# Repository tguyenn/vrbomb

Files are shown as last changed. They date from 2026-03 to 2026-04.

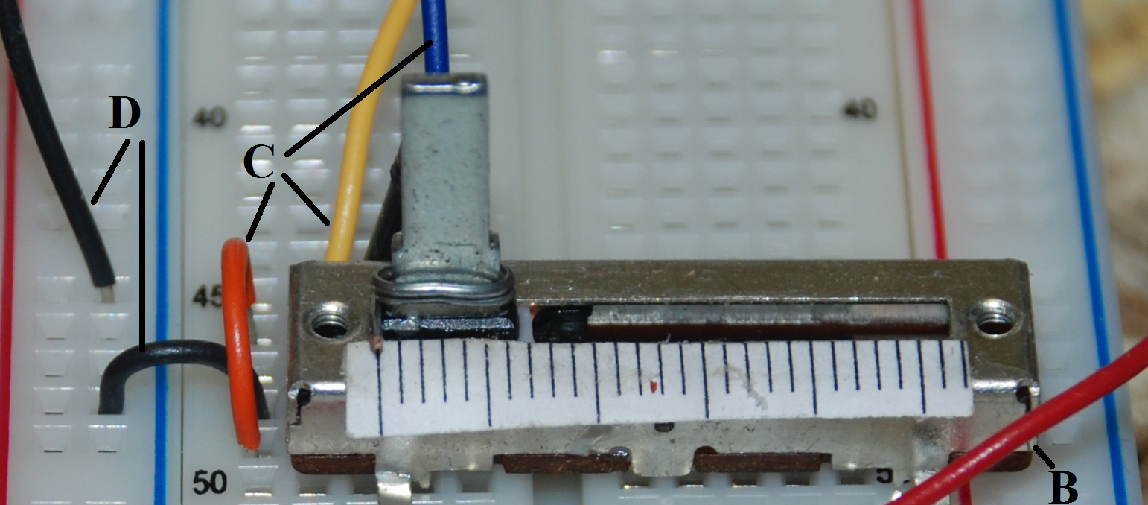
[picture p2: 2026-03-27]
firmware/Main_Board/Lab7_slidepot.png

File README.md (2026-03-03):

Review Assignment Due Date (https://classroom.github.com/a/UF6_VorU)
## 0 Repository Structure

The typical explanation for the repo structure. Lab specific instructions can be
found further below.

### 0.1 HW

The `hw` folder should contain your schematic and board files for your PCB or
circuits. In labs 1-5 and 10, you will be creating schematics for your circuit
in KiCad. 

### 0.2 SW

The `sw` folder should contain your application firmware and software written
for the lab. The `sw/inc` folder contains firmware drivers written for you by
Professor Valvano. Feel free to write your own (in fact, in some labs, you may
be required to write your own).

You can place any other source files in the `sw` folder. TAs will look at the
files you create and/or modify for software quality and for running your
project.

### 0.3 Resources

A couple files are provided in the Resources folder so you don't have to keep
searching for that one TI document. Some of them are immediately useful, like
the TM4C datasheet. Others may be useful for your final project, like the
TM4C_System_Design_Guidelines page.

### 0.4 Git and Github

We will extensively use Git and Github for managing lab projects. This makes it
easier for TAs to grade and help debug the project by allowing us to see commit
histories, maintain a common project structure, and likewise, it makes it easier
for students to collaborate with partners, merge different codebases, and to
debug their work by having a history of commits.

Two common ways of using Git and Github are [Github Desktop](https://desktop.github.com/) and the [command line](https://git-scm.com/downloads).
[Tutorials](https://dev.to/mollynem/git-github--workflow-fundamentals-5496) are also abundant on the net for you to peruse. We've provided a cheatsheet for git
in the Resources folder.

It is highly recommended to make the most out of Git, even if you've never used
it before. Version control will save you a lot of suffering, and tools like Git
or SVN are ubiquitous in the industry.

A gitignore file is added to the root of this repo that may prevent specific
files from being tagged to the repo. This are typically autogenerated output
files we don't care about, but sometimes other stuff (like .lib files) falls
through that we want. Feel free to modify if necessary.

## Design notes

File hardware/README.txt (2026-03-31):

- please pretty please order 10 of our peripheral boards

- look inside each project directory for production files 

thank you :)

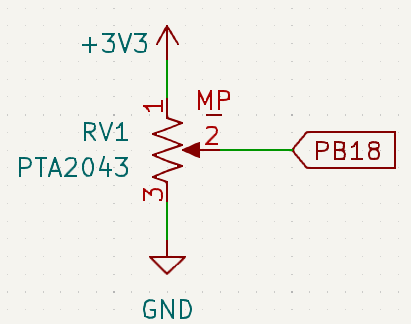
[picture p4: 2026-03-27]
firmware/Main_Board/Lab7Circuit.png

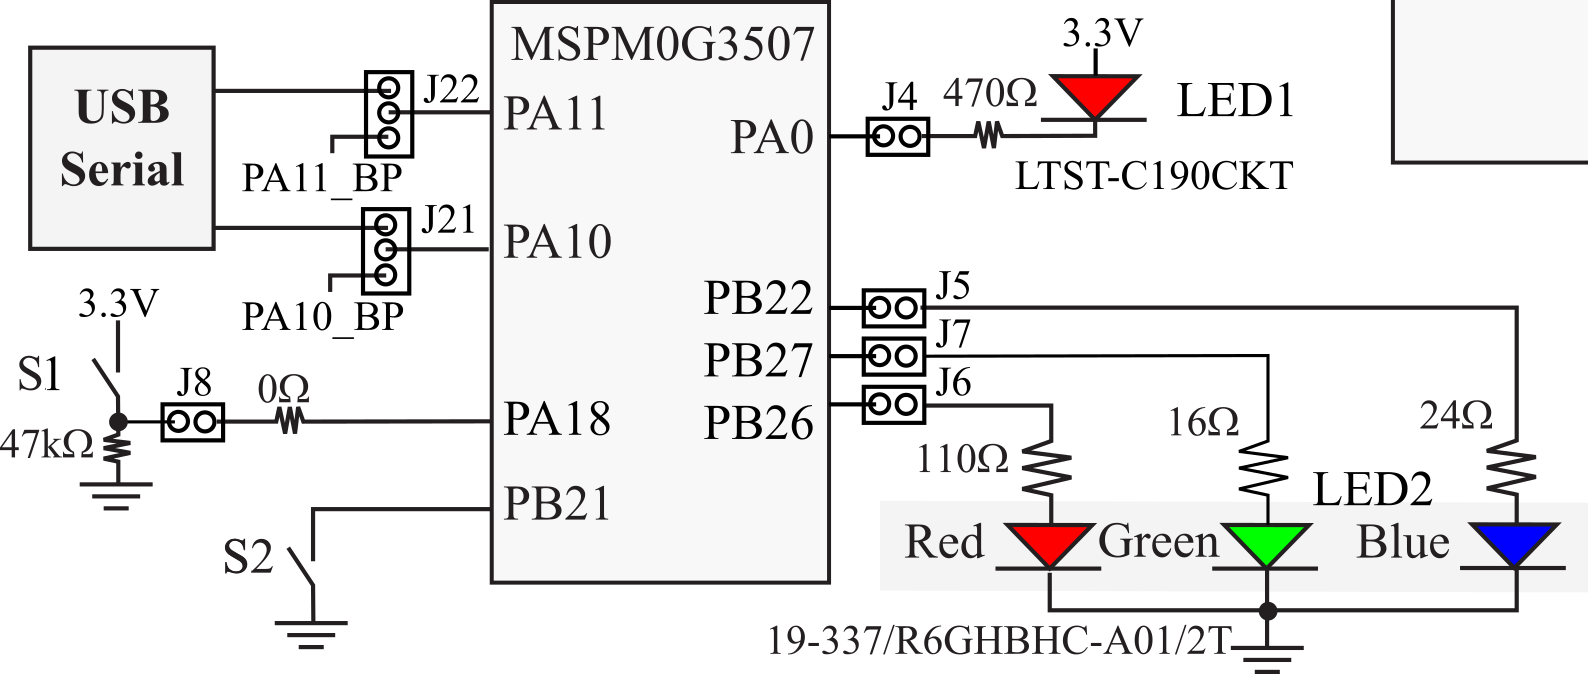
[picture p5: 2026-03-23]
firmware/inc/LaunchPad.png

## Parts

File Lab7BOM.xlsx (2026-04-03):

Bill of Materials |  |  | 2025-01-07 | "not free" means you have to buy it |  | "free sample" means you have to order it
ECE445L Spring 2025 |  |  | EE445L pays for the PCB | "Cabinet means in one of the six black cabinets in professsor's office (bring a print out of your SCH")
 |  |  |  | "Professor" means ask your professor quantity and style will vary (bring a print out of your SCH circuit)
Qty Note | REF DES Note (http://projects.ece.utexas.edu/valvano/wiki/doku.php?id=pcbartist:schematics) |  |  | "Box means in box in your professor's office (bring a print out of your SCH circuit)
Quantity | REF DES | Type | Description | Mfg. P/N | Distributor | P/N | Unit cost | Cost | Where to get it?
60 |  |  | Magnets | - | Mouser | https://www.amazon.com/gp/product/B0CCXY6WBR/ref=ewc_pr_img_1?smid=AFDVT2Q21V43E&th=1 | $0.20 | $11.99
60 |  |  | Hall Effect Sensors | AH49HNTR-G1 | Mouser | https://www.mouser.com/ProductDetail/Diodes-Incorporated/AH49HNTR-G1?qs=M%2FOdCRO8QQ2grA%252BZedkP6g%3D%3D | $0.29 | $17.58
1 |  |  | ADC0 | MCP3221A0T-E/OT | Mouser | https://www.mouser.com/ProductDetail/Microchip-Technology/MCP3221A0T-E-OT?qs=uHi2%2FQoPa5CCFao9voYVSg%3D%3D | $1.91 | $1.91 | 5 copies of ADC because different address requires different part lol
1 |  |  | ADC1 | MCP3221A1T-E/OT | Mouser | https://www.mouser.com/ProductDetail/Microchip-Technology/MCP3221A1T-E-OT?qs=7SaOZgBIvytsewuKZ0dUjA%3D%3D | $1.91 | $1.91
1 |  |  | ADC2 | MCP3221A2T-E/OT | Mouser | https://www.mouser.com/ProductDetail/Microchip-Technology/MCP3221A2T-E-OT?qs=7SaOZgBIvyvHmCSoHmvp%2FA%3D%3D | $1.91 | $1.91
1 |  |  | ADC3 | MCP3221A4T-E/OT | Mouser | https://www.mouser.com/ProductDetail/Microchip-Technology/MCP3221A4T-E-OT?qs=uHi2%2FQoPa5A0hdg9CKvRxA%3D%3D | $1.91 | $1.91 | variant with addr=3 is not available |  | unit cost was incorrect from some items - we should be under budget
1 |  |  | ADC4 | MCP3221A5T-E/OT | Mouser | https://www.mouser.com/ProductDetail/Microchip-Technology/MCP3221A5T-E-OT?qs=InakTnyiSK9lljladcdZHQ%3D%3D | $1.91 | $1.91 |  | $65.04
5 |  |  | ADC Analog Mux | CD74HC4067SM96 | Mouser | https://www.mouser.com/ProductDetail/Texas-Instruments/CD74HC4067SM96?qs=JHHQeKcAU3DyfvAOSRLjhQ%3D%3D | $0.45 | $2.25
70 |  |  | 1u C | 0805YC105KAT2A | Mouser | https://www.mouser.com/ProductDetail/KYOCERA-AVX/0805YC105KAT2A?qs=Ppq%252BQS%252B9qgKbltvIecMi5g%3D%3D | $0.04 | $3.01
10 |  |  | 4u7 C | - | Mouser | - | $0.00 | $0.00 | ECE Checkout
5 |  |  | LDO | LM2937ET-3.3_NOPB | Mouser |  | $0.00 | $0.00 | ECE Checkout
0 |  |  | 1k3 R | RK73B1JTTDD132J | Mouser | https://www.mouser.com/ProductDetail/KOA-Speer/RK73B1JTTDD132J?qs=eQc%252BYniTHCdkD2zz5oX%2F9A%3D%3D | $0.11 | $0.00 | used for test, not final product
0 |  |  | 1k5 R | ESR03EZPJ152 | Mouser | https://www.mouser.com/ProductDetail/ROHM-Semiconductor/ESR03EZPJ152?qs=DyUWGjl%252BcVvm2NOHIcQYzQ%3D%3D | $0.14 | $0.00 | used for test, not final product
0 |  |  | 2k R | ERJ-P06J202V | Mouser | https://www.mouser.com/ProductDetail/Panasonic/ERJ-P06J202V?qs=Zyl8A9hlmJqAy%252BsXwxGx%252BA%3D%3D | $0.12 | $0.00 | used for test, not final product
0 |  |  | 3k R | CRCW08053K00FKTA | Mouser | https://www.mouser.com/ProductDetail/Vishay/CRCW08053K00FKTA?qs=2kV0shNyW70dht2ijvgurw%3D%3D | $0.18 | $0.00 | used for test, not final product
0 |  |  | 3k3 R | CR0805-FX-3301ELF | Mouser | https://www.mouser.com/ProductDetail/Bourns/CR0805-FX-3301ELF?qs=4vGXhLEMbUy96oT8I4L5Pg%3D%3D | $0.10 | $0.00 | used for test, not final product
0 |  |  | 7k5 R | CR0805-FX-7501ELF | Mouser | https://www.mouser.com/ProductDetail/Bourns/CR0805-FX-7501ELF?qs=Ek4EPvi0xiD%252BUX1D91D2cA%3D%3D | $0.10 | $0.00 | used for test, not final product
0 |  |  | 9k1 R | ERJ-6ENF9101V | Mouser | https://www.mouser.com/ProductDetail/Panasonic/ERJ-6ENF9101V?qs=8%252BG0TiN%2FgVqZTf2ghggS7Q%3D%3D | $0.11 | $0.00 | used for test, not final product
1 |  |  | LED | LS R976-NR-1 | Mouser | https://www.mouser.co.uk/ProductDetail/ams-OSRAM/LS-R976-NR-1?qs=K5ta8V%252BWhtZhvCAe1sTZFg%3D%3D | $0.15 | $0.15
1 |  |  | 470 R | AF0805JR-07470RL | Mouser | https://www.mouser.com/ProductDetail/YAGEO/AF0805JR-07470RL?qs=tggtontpCXOaQg0VhtuXeg%3D%3D | $0.10 | $0.10
 |  |  |  |  | Mouser |  |  | $0.00
2 |  |  | Rotary Encoder | KY-040 | Mouser | - | $0.00 | $0.00 | Professor
1 |  |  | Stereo Headphone Jack | - | Mouser | - | $0.00 | $0.00 | ECE Checkout
1 |  |  | LED String | - | Mouser | https://www.amazon.com/gp/product/B088BPGMXB/ref=ox_sc_act_title_1?smid=A35UAT07QG3EC6&th=1 | $14.95 | $14.95
1 |  |  | DC Barrel Jack | 375 | Mouser | https://www.mouser.com/ProductDetail/Adafruit/373?qs=GURawfaeGuDDC%2FyE6Usrdw%3D%3D | $0.95 | $0.95
1 |  |  | LDO | - | Mouser | http://www.ti.com/general/docs/suppproductinfo.tsp?distId=10 | $0.00 | $0.00 | ECE Checkout
2 |  |  | 4u7 C | - | Mouser | - | $0.00 | $0.00 | ECE Checkout
1 |  |  | MSPM0 Chip | M0G3507QDGS32RQ1 | Mouser |  |  | $0.00
1 |  |  | Speaker Amp | LM4890M_NOPB | Mouser |  |  | $0.00
1 |  |  | Level Shift | SN74AHCT125DBR | Mouser | https://www.mouser.com/ProductDetail/Texas-Instruments/SN74AHCT125DBR?qs=b0gIXGU74fMvWnx5K%2FP5XQ%3D%3D | $0.42 | $0.42
1 |  |  | DC Barrel Jack | 373 | Mouser | https://www.mouser.com/ProductDetail/Adafruit/373?qs=GURawfaeGuDDC%2FyE6Usrdw%3D%3D | $0.95 | $0.95
1 |  |  | 3.5 mm Audio Jack | - | Mouser |  | $0.00 | $0.00
1 |  |  | HIletgo LCD | - | Mouser |  | $0.00 | $0.00
6 |  |  | LED | LS R976-NR-1 | Mouser | https://www.mouser.co.uk/ProductDetail/ams-OSRAM/LS-R976-NR-1?qs=K5ta8V%252BWhtZhvCAe1sTZFg%3D%3D | $0.15 | $0.90
2 |  |  | 470 R | AF0805JR-07470RL | Mouser | https://www.mouser.com/ProductDetail/YAGEO/AF0805JR-07470RL?qs=tggtontpCXOaQg0VhtuXeg%3D%3D | $0.10 | $0.20
1 |  |  | 47k R | RC0805JR-7W47KL | Mouser | https://www.mouser.com/ProductDetail/YAGEO/RC0805JR-7W47KL?qs=tggtontpCXNoMeTIW8%252BKHA%3D%3D | $0.10 | $0.10
4 |  |  | 10k R | RV0805JR-0710KL | Mouser | https://www.mouser.com/ProductDetail/YAGEO/RV0805JR-0710KL?qs=qpJ%252B%252B%252Bdg6p3bGiIDT3p%252B0w%3D%3D | $0.10 | $0.40
4 |  |  | 5k R | CRCW08055K00JNTA | Mouser | https://www.mouser.com/ProductDetail/Vishay/CRCW08055K00JNTA?qs=ypDtOmddc9yTg%252BhfBkNNHg%3D%3D | $0.14 | $0.56
2 |  |  | 20k R | CRCW08055K00JNTA | Mouser | https://www.mouser.com/ProductDetail/Vishay/CRCW08055K00JNTA?qs=ypDtOmddc9yTg%252BhfBkNNHg%3D%3D | $0.10 | $0.20
1 |  |  | 10n C | C0805C103K1RAC7411 | Mouser | https://www.mouser.com/ProductDetail/KEMET/C0805C103K1RAC7411?qs=jbRM9o5BbzN%252BKAvowF%2FE%2Fw%3D%3D | $0.10 | $0.10
2 |  |  | 10u C | CL21A106KPFNNNE | Mouser | https://www.mouser.com/ProductDetail/Samsung-Electro-Mechanics/CL21A106KPFNNNE | $0.10 | $0.20
1 |  |  | 0u1 C | MG21B104K500CT | Mouser | https://www.mouser.com/ProductDetail/Walsin/MG21B104K500CT | $0.10 | $0.10
1 |  |  | 0u47 C | CL10B474KO8NFNC | Mouser | https://www.mouser.com/ProductDetail/Samsung-Electro-Mechanics/CL10B474KO8NFNC | $0.12 | $0.12
4 |  |  | 1u C | 0805YC105KAT2A | Mouser | https://www.mouser.com/ProductDetail/KYOCERA-AVX/0805YC105KAT2A?qs=Ppq%252BQS%252B9qgKbltvIecMi5g%3D%3D | $0.04 | $0.17
1 |  |  | 0u33 C | GRM033R60J334ME90D | Mouser | https://www.mouser.com/ProductDetail/Murata-Electronics/GRM033R60J334ME90D | $0.10 | $0.10
1 |  |  | Switch | - | Mouser |  | $0.00 | $0.00
0
0
0
0
0
0
0
0
0
0
0
0
0
0
0
0
0
0
0
0
0
0
0
0
0
0
0
0
0
0
0
0
0
0
0
0
0
0
0
0
0
0
0
0
0
0
0
0
0
0
0
0
0
0
0
0
0
0
0
0
0
0
0
0
0
0
0
0
0
0
0
0
0
0
0
0
0
0
0
0
0
0
0
0
0
0
0
0
0
0
0
0
0
0
0
0
0
0
0
0
0
0
0

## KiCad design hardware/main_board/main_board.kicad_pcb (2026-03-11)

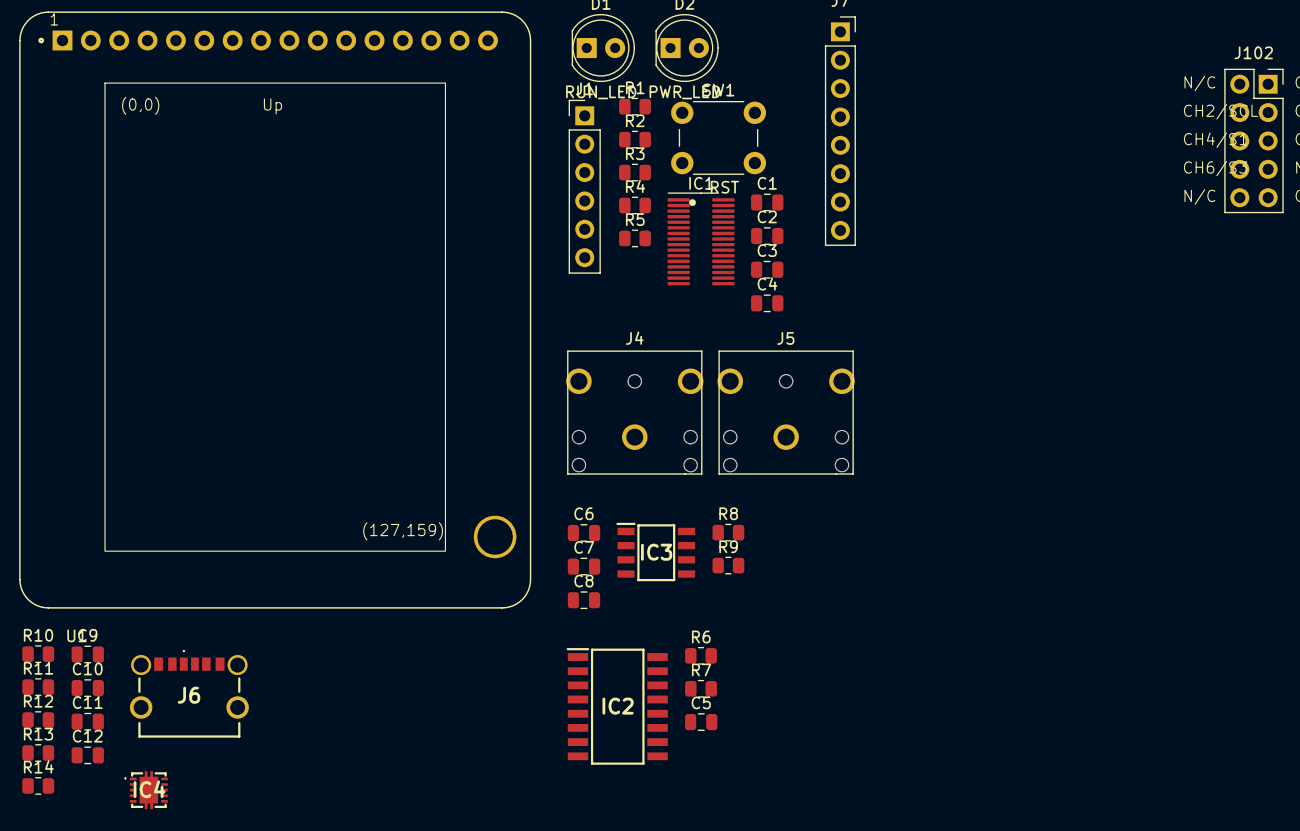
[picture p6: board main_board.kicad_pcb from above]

Board: 2 copper layers, 40 parts (0 on the bottom side), 41 nets, no tracks yet.

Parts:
C1: 0.47uF; C_0805_2012Metric
C2: 10nF; C_0805_2012Metric
C3: 10uF; C_0805_2012Metric
C4: 0.1uF; C_0805_2012Metric
C5, C6, C8: 1u; C_0805_2012Metric
C7: 0u33; C_0805_2012Metric
C9, C10, C11: 10u; C_0805_2012Metric
C12: u1; C_0805_2012Metric
D1: RUN_LED; LED_D5.0mm
D2: PWR_LED; LED_D5.0mm
IC1: M0G3507QDGS32RQ1; generic_VSSOP_0.5mm
IC2: SN74HC157NSR; SOIC127P780X200-16N
IC3: LM4890M_NOPB; ti_LM4890M_NOPB
IC4: TPS63000IDRCRQ1
J1: Conn_01x06_Pin; PinHeader_1x06_P2.54mm_Vertical
J4, J5: AudioJack; Jack_3.5mm_CUI_SJ1-3523N_Horizontal
J6: UJC-H-G-SMT-1-P6-TR; UJCHGSMT1P6TR
J7: 1x8 Male Pins; PinSocket_1x08_P2.54mm_Vertical
J102: 2x5 Socket Pins; PinSocket_2x05_P2.54mm_Vertical
R1, R2, R6, R7: 10k; R_0805_2012Metric
R3: 47k; R_0805_2012Metric
R4, R5: 470; R_0805_2012Metric
R8, R9: 20k; R_0805_2012Metric
R10: 100; R_0805_2012Metric
R11: 1M; R_0805_2012Metric
R12, R13: 5k1; R_0805_2012Metric
R14: 200k; R_0805_2012Metric
SW1: RST; SW_PUSH_6mm
U1: HiLetGo_ST7735R; hiletgo_st7735r

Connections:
+3V3: C3.1, C4.1, C10.1, C11.1, IC1.7 (VDD), IC4.1 (VOUT), J1.5, R1.2, R2.2, R3.1, R5.1, R6.2, R7.2, R11.1, U1.2 (VCC), U1.6 (RESET), U1.15 (LED+)
+5V: C6.2, C9.1, IC3.6 (VDD), IC4.5 (VIN), J6.A9 (VBUS), J6.B9 (VBUS), J7.1, R10.1
/Audio IO/ADC_IN: IC1.21 (PA14/CLK_OUT/A0_12), J5.R (ring), J5.T (tip)
/Audio IO/DAC_OUT: C7.1, IC1.22 (PA15/A1_0/DACOUT)
/Encoders & Buttons/ENC1.SW: IC2.2 (1A), R6.1
/Encoders & Buttons/ENC2.SW: IC2.3 (1B), R7.1
/Encoders & Buttons/ENC.CLK: IC1.1 (PA26/A0_1), IC2.9 (3Y)
/Encoders & Buttons/ENC.DT: IC1.2 (PA27/RTC_OUT/A0_0), IC2.7 (2Y)
/Encoders & Buttons/ENC.SW: IC1.28 (PA21/A1_7/VREF-), IC2.4 (1Y)
/Encoders & Buttons/ENC_TOGGLE: IC1.32 (PA25/A0_2), IC2.1 (~A/B)
/LCD/CS_LCD: IC1.10 (PA3/LFXIN), U1.10 (TFT_CS)
/LCD/CS_SD: IC1.9 (PA2/ROSC), U1.14 (SDC_CS)
/LCD/LCD_DC: IC1.14 (PA7/CLK_OUT), U1.7 (TFTDC)
/LCD/SPI0.MISO: IC1.11 (PA4/LFCLK_IN/LFXOUT), U1.12 (SDC_MISO)
/LCD/SPI0.MOSI: IC1.12 (PA5/HFXIN/FCC_IN), U1.8 (TFTMOSI), U1.13 (SDC_MOSI)
/LCD/SPI0.SCK: IC1.13 (PA6/HFCLK_IN/HFXOUT), U1.9 (TFTSCK), U1.11 (SDCSCK)
/MCU/BSL_INVOKE: IC1.25 (PA18/A1_3), J1.1
/MCU/I2C0.SCL: IC1.5 (PA1), R1.1
/MCU/I2C0.SDA: IC1.4 (PA0), R2.1
/MCU/NRST: C2.1, IC1.6 (NRST), J1.4, R3.2, SW1.2
/MCU/RUN_LED: IC1.15 (PA8), R4.1
/MCU/S0: IC1.17 (PA10/CLK_OUT), J7.4
/MCU/S1: IC1.18 (PA11), J7.5
/MCU/S2: IC1.19 (PA12/FCC_IN), J7.6
/MCU/S3: IC1.20 (PA13), J7.7
/MCU/SWCLK: IC1.27 (PA20/SWCLK), J1.2
/MCU/SWDIO: IC1.26 (PA19/SWDIO), J1.3
GND: C1.2, C2.2, C3.2, C4.2, C5.2, C6.1, C8.2, C12.2, D1.1 (K), D2.1 (K), IC1.8 (VSS), IC2.8 (GND), IC2.15 (~G), IC3.1 (~SHUTDOWN), IC3.7 (GND), IC4.9 (GND), J1.6, J4.S (sleeve), J5.S (sleeve), J6.A12 (GND), J6.B12 (GND), J7.8, J102.9, R12.2, R13.2, R14.2, SW1.1, U1.1 (GND), U1.16 (LED-)
GNDPWR: C9.2, C10.2, C11.2, IC4.3 (PGND_1), IC4.11 (PGND_2), IC4.12 (PGND_3), IC4.13 (PGND_4), IC4.14 (PGND_5), IC4.15 (PGND_6)
unnamed: C7.2, R8.1
unnamed: D1.2 (A), R4.2
unnamed: D2.2 (A), R5.2
unnamed: C1.1, IC1.3 (VCORE)
unnamed: C5.1, IC2.16 (VCC)
unnamed: C8.1, IC3.2 (BYPASS), IC3.3 (+IN)
unnamed: IC3.4 (-IN), R8.2, R9.1
unnamed: IC3.5 (VO_1), J4.R (ring), J4.T (tip), R9.2
unnamed: C12.1, IC4.6 (EN), IC4.7 (PS/SYNC), IC4.8 (VINA), R10.2
unnamed: IC4.10 (FB), R11.2, R14.1
unnamed: J6.A5 (CC1), R13.1
unnamed: J6.B5 (CC2), R12.1

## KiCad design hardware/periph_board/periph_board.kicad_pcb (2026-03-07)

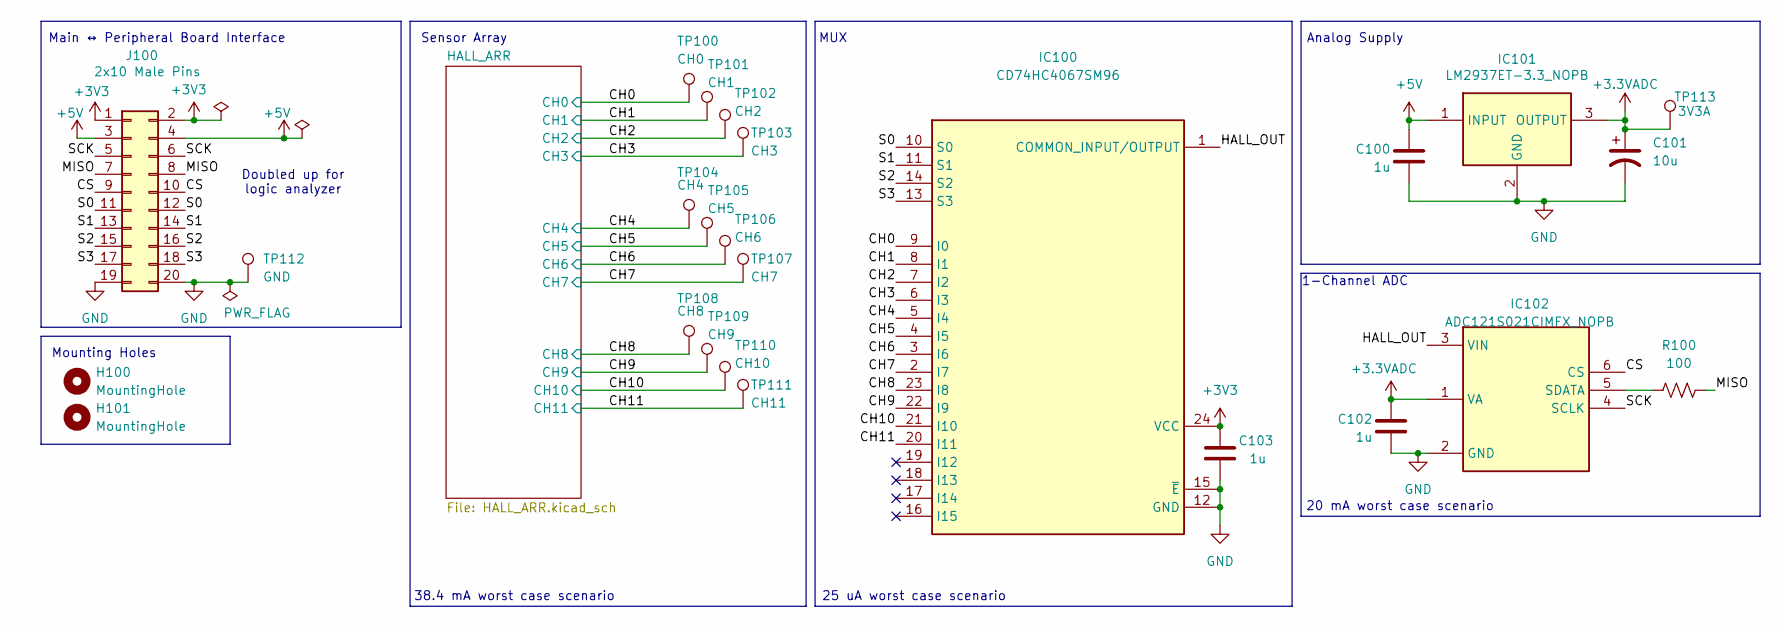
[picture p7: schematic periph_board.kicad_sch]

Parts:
C100, C102, C103: 1u; C_0805_2012Metric_Pad1.18x1.45mm_HandSolder
C101: 10u; C_0805_2012Metric
H100, H101: MountingHole; MountingHole_3.2mm_M3
IC100: CD74HC4067SM96; SOP65P780X200-24N; Mouser Part Number 595-CD74HC4067SM96
IC101: LM2937ET-3.3_NOPB; TO254P470X1028X1955-3P; Mouser Part Number 926-LM2937ET-3.3NOPB
IC102: ADC121S021CIMFX_NOPB; SOT95P280X145-6N; Mouser Part Number 926-A121S021CIMFXNPB
J100: 2x10 Male Pins; PinSocket_2x10_P2.54mm_Vertical
R100: 100; R_0805_2012Metric
TP100: CH0; bettertestpoint2
TP101: CH1; bettertestpoint2
TP102: CH2; bettertestpoint2
TP103: CH3; bettertestpoint2
TP104: CH4; bettertestpoint2
TP105: CH5; bettertestpoint2
TP106: CH6; bettertestpoint2
TP107: CH7; bettertestpoint2
TP108: CH8; bettertestpoint2
TP109: CH9; bettertestpoint2
TP110: CH10; bettertestpoint2
TP111: CH11; bettertestpoint2
TP112: GND; bettertestpoint2
TP113: 3V3A; bettertestpoint2

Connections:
+3.3VADC: C101.1, C102.2, IC101.3 (OUTPUT), IC102.1 (VA), TP113.1
+3V3: C103.2, IC100.24 (VCC), J100.1, J100.2; also elsewhere on the board
+5V: C100.2, IC101.1 (INPUT), J100.3, J100.4
/CH0: IC100.9 (I0), TP100.1; also elsewhere on the board
/CH1: IC100.8 (I1), TP101.1; also elsewhere on the board
/CH2: IC100.7 (I2), TP102.1; also elsewhere on the board
/CH3: IC100.6 (I3), TP103.1; also elsewhere on the board
/CH4: IC100.5 (I4), TP104.1; also elsewhere on the board
/CH5: IC100.4 (I5), TP105.1; also elsewhere on the board
/CH6: IC100.3 (I6), TP106.1; also elsewhere on the board
/CH7: IC100.2 (I7), TP107.1; also elsewhere on the board
/CH8: IC100.23 (I8), TP108.1; also elsewhere on the board
/CH9: IC100.22 (I9), TP109.1; also elsewhere on the board
/CH10: IC100.21 (I10), TP110.1; also elsewhere on the board
/CH11: IC100.20 (I11), TP111.1; also elsewhere on the board
/CS: IC102.6 (CS), J100.9, J100.10
/HALL_OUT: IC100.1 (COMMON_INPUT/OUTPUT), IC102.3 (VIN)
/MISO: J100.7, J100.8, R100.2
/S0: IC100.10 (S0), J100.11, J100.12
/S1: IC100.11 (S1), J100.13, J100.14
/S2: IC100.14 (S2), J100.15, J100.16
/S3: IC100.13 (S3), J100.17, J100.18
/SCK: IC102.4 (SCLK), J100.5, J100.6
GND: C100.1, C101.2, C102.1, C103.1, IC100.12 (GND), IC100.15 (~E), IC101.2 (GND), IC102.2 (GND), J100.19, J100.20, TP112.1; also elsewhere on the board
unnamed: IC102.5 (SDATA), R100.1

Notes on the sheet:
Mounting Holes
MUX
Analog Supply
Main ↔ Peripheral Board Interface
38.4 mA worst case scenario
1-Channel ADC
20 mA worst case scenario
Sensor Array
Doubled up for logic analyzer
25 uA worst case scenario

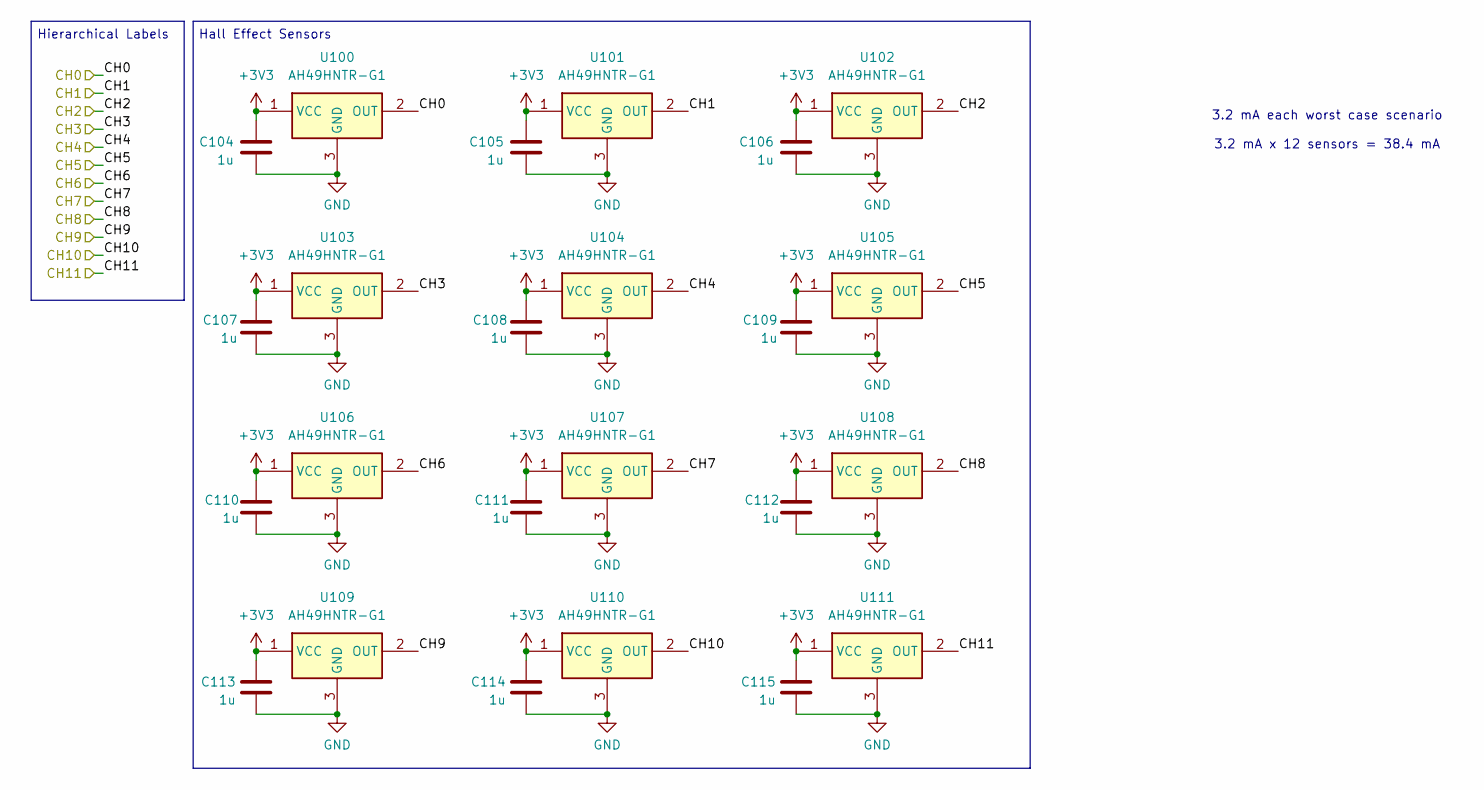
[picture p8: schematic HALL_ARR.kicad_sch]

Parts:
C104, C105, C106, C107, C108, C109, C110, C111, C112, C113, C114, C115: 1u; C_0805_2012Metric_Pad1.18x1.45mm_HandSolder
U100, U101, U102, U103, U104, U105, U106, U107, U108, U109, U110, U111: AH49HNTR-G1; SOT95P282X145-3N; Mouser Part Number 621-AH49HNTR-G1

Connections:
+3V3: C104.2, C105.2, C106.2, C107.2, C108.2, C109.2, C110.2, C111.2, C112.2, C113.2, C114.2, C115.2, U100.1 (VCC), U101.1 (VCC), U102.1 (VCC), U103.1 (VCC), U104.1 (VCC), U105.1 (VCC), U106.1 (VCC), U107.1 (VCC), U108.1 (VCC), U109.1 (VCC), U110.1 (VCC), U111.1 (VCC); also elsewhere on the board
/CH0: U100.2 (OUT); also elsewhere on the board
/CH1: U101.2 (OUT); also elsewhere on the board
/CH2: U102.2 (OUT); also elsewhere on the board
/CH3: U103.2 (OUT); also elsewhere on the board
/CH4: U104.2 (OUT); also elsewhere on the board
/CH5: U105.2 (OUT); also elsewhere on the board
/CH6: U106.2 (OUT); also elsewhere on the board
/CH7: U107.2 (OUT); also elsewhere on the board
/CH8: U108.2 (OUT); also elsewhere on the board
/CH9: U109.2 (OUT); also elsewhere on the board
/CH10: U110.2 (OUT); also elsewhere on the board
/CH11: U111.2 (OUT); also elsewhere on the board
GND: C104.1, C105.1, C106.1, C107.1, C108.1, C109.1, C110.1, C111.1, C112.1, C113.1, C114.1, C115.1, U100.3 (GND), U101.3 (GND), U102.3 (GND), U103.3 (GND), U104.3 (GND), U105.3 (GND), U106.3 (GND), U107.3 (GND), U108.3 (GND), U109.3 (GND), U110.3 (GND), U111.3 (GND); also elsewhere on the board

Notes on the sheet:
3.2 mA each worst case scenario 3.2 mA x 12 sensors = 38.4 mA
Hall Effect Sensors
Hierarchical Labels

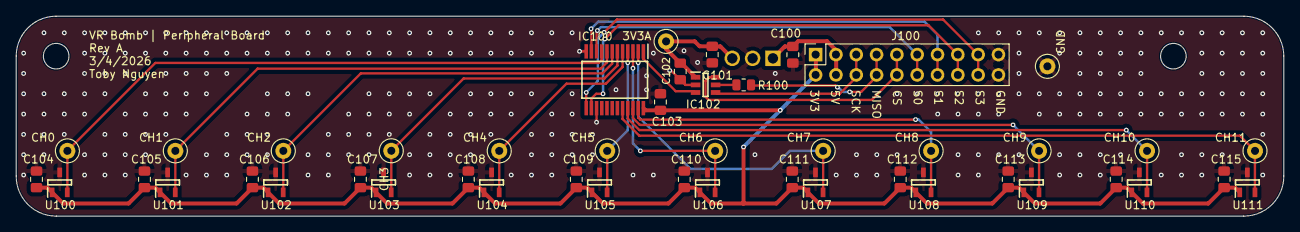
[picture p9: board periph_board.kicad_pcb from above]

Board: 2 copper layers, 158.5 x 25.0 mm, 49 parts (1 on the bottom side), 25 nets.

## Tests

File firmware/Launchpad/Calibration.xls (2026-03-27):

 | Do this calibration yourself
 | y | x | x^2 | x*y
 | Position (0.001 cm) | ADC Data |  |  | Fitted Position (0.001cm) | Error | percent
 | 100 | 538 | 289444 | 53800 | 84 | -0.016 | 1.60%
 | 400 | 1295 | 1677025 | 518000 | 421 | 0.021 | 2.10%
 | 800 | 2140 | 4579600 | 1712000 | 798 | -0.002 | 0.20%
 | 1200 | 3050 | 9302500 | 3660000 | 1203 | 0.003 | 0.30%
 | 1400 | 3474 | 12068676 | 4863600 | 1392 | -0.008 | 0.80%
Sum | 3900 | 10497 | 27917245 | 10807400
 | n | 5 |  |  |  | Ave | 1.00%
 | m | 0.4455458948
 | b | -155.3790516
 | 12 bit | 4096
 | k1 | 1825
 | k2 | -155

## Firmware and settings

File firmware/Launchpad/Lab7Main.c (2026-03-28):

// Lab7Main.c
// Runs on MSPM0G3507
// Lab 7
// Your name
// Last Modified: January 12, 2026

// #include "../inc/ADC1.h"
#include "../inc/Clock.h"
#include "../inc/LaunchPad.h"
#include "../inc/ST7735.h"
#include "../inc/Texas.h"
#include "../inc/Timer.h"
#include <stdint.h>
#include <stdio.h>
#include <ti/devices/msp/msp.h>

// ****note to ECE319K students****
// the data sheet says the ADC does not work when clock is 80 MHz
// however, the ADC seems to work on my boards at 80 MHz
// I suggest you try 80MHz, but if it doesn't work, switch to 40MHz
void PLL_Init(void) { // set phase lock loop (PLL)
  // Clock_Init40MHz(); // run this line for 40MHz
  Clock_Init80MHz(0); // run this line for 80MHz
}

// // implement this function
// void OutFix(uint32_t n){
// // resolution is 0.001cm
// // n is integer 0 to 2000
// // output to ST7735 0.000cm to 2.000cm
//  // write this
// }

// // do not use this function for your final lab solution
// // it is added just to show you how SLOW floating point is on a Cortex M0+
// void FloatOutFix(float x){
// // resolution cm
// // x is integer 0 to 2.000
// // output to ST7735 0.000cm to 2.000cm
//   printf("d=%f cm   ",x);  // floating point output
// }

// uint32_t Data;        // 12-bit ADC
// uint32_t Position;    // 32-bit fixed-point 0.001 cm
// float FloatPosition;  // 32-bit floating-point cm
//  // define a semaphore
// uint32_t startTime,stopTime;
// uint32_t
// Offset,ADCtime,Converttime,FloatConverttime,OutFixtime,FloatOutFixtime; // in
// bus cycles uint32_t Time;
// // use main1 if you do not have a voltmeter
// // use main1 to test slidepot interface
// // connect slidepot pin 2 to ADC1 channel 5, PB18
// // Open TExaSdisplay and see slidepot pin2 go from 0 to 3.3V

// --------------- TEST CODE FOR 445L ---------------------
// Test analog mux selection of hall effect, 2 hall effect sensors are actually
// attached for testing purposes

int main(void) { // main1
  __disable_irq();
  PLL_Init(); // set bus speed
  LaunchPad_Init();
  // TExaS_Init(ADC1, 5, 0); // ADC1 channel 5, PB18, slidepot
  // ST7735_InitR(INITR_REDTAB);
  __enable_irq();

  // ST7735_FillScreen(ST7735_BLACK);

  while (1) {
    // ST7735_OutUDec4(i);
    static uint32_t i = 0;
    if (i > 15)
      i = 0;

    // GPIOB->DOUT31_0 = 0;

    switch (i) {
    case 0:
      GPIOB->DOUT31_0 = 0x000; // All off
      break;
    case 1:
      GPIOB->DOUT31_0 = 0x001; // PB0
      break;
    case 2:
      GPIOB->DOUT31_0 = 0x040; // PB6
      break;
    case 3:
      GPIOB->DOUT31_0 = 0x041; // PB6, PB0
      break;
    case 4:
      GPIOB->DOUT31_0 = 0x080; // PB7
      break;
    case 5:
      GPIOB->DOUT31_0 = 0x081; // PB7, PB0
      break;
    case 6:
      GPIOB->DOUT31_0 = 0x0C0; // PB7, PB6
      break;
    case 7:
      GPIOB->DOUT31_0 = 0x0C1; // PB7, PB6, PB0
      break;
    case 8:
      GPIOB->DOUT31_0 = 0x100; // PB8
      break;
    case 9:
      GPIOB->DOUT31_0 = 0x101; // PB8, PB0
      break;
    case 10:
      GPIOB->DOUT31_0 = 0x140; // PB8, PB6
      break;
    case 11:
      GPIOB->DOUT31_0 = 0x141; // PB8, PB6, PB0
      break;
    case 12:
      GPIOB->DOUT31_0 = 0x180; // PB8, PB7
      break;
    case 13:
      GPIOB->DOUT31_0 = 0x181; // PB8, PB7, PB0
      break;
    case 14:
      GPIOB->DOUT31_0 = 0x1C0; // PB8, PB7, PB6
      break;
    case 15:
      GPIOB->DOUT31_0 = 0x1C1; // PB8, PB7, PB6, PB0
      break;
    }

    i++;

    // Simple wait
    for (int j = 0; j < 100000; j++) {
      __asm("NOP");
    }
  }
}
// // if you have a voltmeter/scope,
// // use the voltmeter/scope see slidepot pin2 go from 0 to 3.3V

// // use main2 to test ADCinit and ADCin functions
// // connect slidepot pin 2 to PB18 ADC1
// // Data should go from 0 to 4095
// // ADCtime is the time to execute ADCin in bus cycles
// // use main2 to calibrate the system fill in 5 points in Calibration.xls
// //    determine constants k1 k2 to fit Position=(k1*Data)>>12 + k2
// int main2(void){ // main2
//   __disable_irq();
//   PLL_Init(); // set bus speed
//   LaunchPad_Init();
//   SysTick->LOAD = 0xFFFFFF;    // max
//   SysTick->VAL = 0;            // any write to current clears it
//   SysTick->CTRL = 0x00000005;  // enable SysTick with core clock
//   startTime = SysTick->VAL;
//   stopTime = SysTick->VAL;
//   Offset = (startTime-stopTime)&0x0FFFFFF; // in bus cycles to perform time
//   measurement ADCinit(); //ADC1 channel 5, PB18, slidepot while(1){
//     startTime = SysTick->VAL;
//     Data = ADCin();  // sample ADC1 channel 5, PB18, slidepot
//     stopTime = SysTick->VAL;
//     ADCtime = ((startTime-stopTime)&0x0FFFFFF)-Offset; // in bus cycles
//   }
// }

// // use main3 to test Convert functions
// // connect slidepot pin 2 to PB18
// // Data should go from 0 to 4095
// // Position should go from 0 to 2000
// // Use main3 to take another 5 measurements to determine accuracy
// // truth is your eyes and the cursor on your slide pot
// // measurement is the Position variable
// // Converttime is the time to execute Convert in bus cycles
// int main3(void){ // main3
//   __disable_irq();
//   PLL_Init(); // set bus speed
//   LaunchPad_Init();
//   SysTick->LOAD = 0xFFFFFF;    // max
//   SysTick->VAL = 0;            // any write to current clears it
//   SysTick->CTRL = 0x00000005;  // enable SysTick with core clock
//   startTime = SysTick->VAL;
//   stopTime = SysTick->VAL;
//   Offset = (startTime-stopTime)&0x0FFFFFF; // in bus cycles to perform time
//   measurement ADCinit(); //PB18 = ADC0 channel 5, slidepot while(1){
//     Data = ADCin();  // sample 12-bit ADC0 channel 5, slidepot
//     startTime = SysTick->VAL;
//     Position = Convert(Data);
//     stopTime = SysTick->VAL;
//     Converttime = ((startTime-stopTime)&0x0FFFFFF)-Offset; // in bus cycles
//     startTime = SysTick->VAL;
//     FloatPosition = FloatConvert(Data);
//     stopTime = SysTick->VAL;
//     FloatConverttime = ((startTime-stopTime)&0x0FFFFFF)-Offset; // in bus
//     cycles
//   }
// }

// // use main4 to test OutFix functions
// // connect slidepot pin 2 to PB18
// // Data should go from 0 to 4095
// // Position should go from 0 to 2000
// // LCD should show 0.000cm to 2.000 cm
// // OutFixtime is the time to execute OutFix in bus cycles
// int main4(void){ // main4
//   __disable_irq();
//   PLL_Init(); // set bus speed
//   LaunchPad_Init();
//   ST7735_InitPrintf(INITR_REDTAB); // INITR_REDTAB for AdaFruit,
//   INITR_BLACKTAB for HiLetGo ST7735_FillScreen(ST7735_BLACK); SysTick->LOAD =
//   0xFFFFFF;    // max SysTick->VAL = 0;            // any write to current
//   clears it SysTick->CTRL = 0x00000005;  // enable SysTick with core clock
//   startTime = SysTick->VAL;
//   stopTime = SysTick->VAL;
//   Offset = (startTime-stopTime)&0x0FFFFFF; // in bus cycles to perform time
//   measurement ADCinit(); //PB18 = ADC0 channel 5, slidepot while(1){
//     ST7735_SetCursor(0,0); // top left
//     Data = ADCin();  // sample 12-bit ADC0 channel 5, slidepot
//     Position = Convert(Data);
//     FloatPosition = FloatConvert(Data);
//     startTime = SysTick->VAL;
//     OutFix(Position);
//     stopTime = SysTick->VAL;
//     OutFixtime = ((startTime-stopTime)&0x0FFFFFF)-Offset; // in bus cycles
//     ST7735_SetCursor(0,1); // second row
//     startTime = SysTick->VAL;
//     FloatOutFix(FloatPosition);
//     stopTime = SysTick->VAL;
//     FloatOutFixtime = ((startTime-stopTime)&0x0FFFFFF)-Offset; // in bus
//     cycles Clock_Delay1ms(100);
//   }
// }
// // sampling frequency is 30 Hz
// void TIMG12_IRQHandler(void){
//   if((TIMG12->CPU_INT.IIDX) == 1){ // this will acknowledge
//     GPIOB->DOUTTGL31_0 = GREEN; // toggle PB27 (minimally intrusive
//     debugging) GPIOB->DOUTTGL31_0 = GREEN; // toggle PB27 (minimally
//     intrusive debugging) Time++;
//     // sample 12-bit ADC0 channel 5, slidepot
//     // store data into mailbox
//     // set the semaphore
//     GPIOB->DOUTTGL31_0 = GREEN; // toggle PB27 (minimally intrusive
//     debugging)
//   }
// }
// uint8_t TExaS_LaunchPadLogicPB27PB26(void){
//   return (0x80|((GPIOB->DOUT31_0>>26)&0x03));
// }
// // use main5 for final system
// // use scope or logic analyzer to verify real time samples
// // option 1) remove call to TExaS_Init and use a real scope on PB27
// // option 2) use TExaS logic analyzer
// int main5(void){ // main5
//   __disable_irq();
//   PLL_Init(); // set bus speed
//   LaunchPad_Init();
//   ST7735_InitPrintf(INITR_REDTAB); // INITR_REDTAB for AdaFruit,
//   INITR_BLACKTAB for HiLetGo ST7735_FillScreen(ST7735_BLACK); ADCinit();
//   //PB18 = ADC1 channel 5, slidepot
//   TExaS_Init(0,0,&TExaS_LaunchPadLogicPB27PB26); // PB27 and PB26
//   ST7735_PlotClear(0,2000);
//     // initialize interrupts on TimerG12 at 30 Hz

//   // initialize semaphore

//   Time = 0;
//   __enable_irq();
//   while(1){
//       // write this

//     // wait for semaphore
//     // clear the semaphore
//     GPIOB->DOUTTGL31_0 = RED; // toggle PB26 (minimally intrusive debugging)
//     // toggle red LED2 on Port B, PB26
//      // convert Data to Position
//      // move cursor to top
//     // display distance in top row OutFix

//     Time++;
//     if((Time%15)==0){
//       ST7735_PlotPoint(Position);
//       ST7735_PlotNextErase(); // data plotted at about 2 Hz
//     }
//   }
// }

// // use main6 to study Central Limit Theorem
// uint32_t Histogram[64]; // probability mass function
// uint32_t Center,SAC;
// #define SCALE 2000
// int main6(void){ // main6
//   __disable_irq();
//   PLL_Init(); // set bus speed
//   LaunchPad_Init();
//   ST7735_InitPrintf(INITR_REDTAB); // INITR_REDTAB for AdaFruit,
//   INITR_BLACKTAB for HiLetGo ST7735_FillScreen(ST7735_BLACK); ADCinit();
//   //PB18 = ADC1 channel 5, slidepot SAC = 1; while(1){int i; uint32_t d,sum;
//     sum = 0;
//     for(int j=0; j<100; j++){
//       sum += ADCin();  // sample 12-bit ADC0 channel 5, slidepot
//     }
//     Center = sum/100; // averaging
//     for(i=0; i<64; i++) Histogram[i] = 0; // clear
//     for(i=0; i<200; i++){
//       sum = 0;
//       for(int j=0; j<SAC; j++){
//         sum += ADCin();  // sample 12-bit ADC0 channel 5, slidepot
//       }
//       Data = sum/SAC; // averaging
//       if(Data<Center-32){
//          Histogram[0]++;
//       }else if(Data>=Center+32){
//          Histogram[63]++;
//       }else{
//         d = Data-Center+32;
//         Histogram[d]++;
//       }
//     }
//     ST7735_PlotClear(0,100);
//     ST7735_SetCursor(0,0);
//     printf("SAC=%3u,Center=%4u",SAC,Center);
//     for(i=0; i<63; i++){
//       if(Histogram[i]>99) Histogram[i]=99;
//       ST7735_PlotBar(Histogram[i]);
//       ST7735_PlotNext();
//       ST7735_PlotBar(Histogram[i]);
//       ST7735_PlotNext();
//     }
//     while(LaunchPad_InS2()==0x00040000){}; // wait for release
//     while(LaunchPad_InS2()==0){};          // wait for touch
//     SAC = SAC<<1;
//     if(SAC >= 256) SAC = 1;
//   }
// }

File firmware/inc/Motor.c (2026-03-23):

/* Motor.c
 * Jonathan Valvano
 * v2.0.2
 * June 28, 2024
// Motor
// TM4C MSPM0
// PF2  PB4  Motor_PWML, ML+, IN3, PB.4/TIMA1_C0;
// PF3  PB1  Motor_PWMR, MR+, IN1, PB.1/TIMA1_C1;
// PA3  PB0  Motor_DIR_L,ML-, IN4, 1 means forward, 0 means backward
// PA2  PB16 Motor_DIR_R,MR-, IN2, ***change from 2.0.0***
 *
 */
#include <ti/devices/msp/msp.h>
#include "../inc/LaunchPad.h"
#include "../inc/Clock.h"
#include "../inc/PWM1.h"
#define DRV8847 1
#define DIR_L 1
#define DIR_R (1<<16)
#define MOTOR_PERIOD 10000
void Motor_Init(void){
  // LaunchPad_Init was called
  IOMUX->SECCFG.PINCM[PB0INDEX] = (uint32_t) 0x00000081;
  IOMUX->SECCFG.PINCM[PB16INDEX] = (uint32_t) 0x00000081;
  // DOE31_0 Data output enable
  GPIOB->DOE31_0 |= (1 | (1<<16)); // enable outputs
  GPIOB->DOUTCLR31_0 = DIR_L | DIR_R;  // forward

  PWM1_Init(PWMUSEBUSCLK,39,MOTOR_PERIOD,MOTOR_PERIOD-4,MOTOR_PERIOD-4); // 100Hz, stopped

}
#if DRV8847
void Motor_Forward(uint32_t dutyLeft, uint32_t dutyRight){
  GPIOB->DOUTCLR31_0 = DIR_L | DIR_R;  // forward
  PWM1_SetDuty(MOTOR_PERIOD-dutyLeft,MOTOR_PERIOD-dutyRight);
}

void Motor_Backward(uint32_t dutyLeft, uint32_t dutyRight){
  GPIOB->DOUTSET31_0 = DIR_L | DIR_R;  // backward
  PWM1_SetDuty(dutyLeft,dutyRight);
}
void Motor_Right(uint32_t dutyLeft, uint32_t dutyRight){
  GPIOB->DOUTCLR31_0 = DIR_L;  // left forward
  GPIOB->DOUTSET31_0 = DIR_R;  // right backward
  PWM1_SetDuty(MOTOR_PERIOD-dutyLeft,dutyRight);
}
void Motor_Left(uint32_t dutyLeft, uint32_t dutyRight){
  GPIOB->DOUTCLR31_0 = DIR_R;  // right forward
  GPIOB->DOUTSET31_0 = DIR_L;  // left backward
  PWM1_SetDuty(dutyLeft,MOTOR_PERIOD-dutyRight);
}
#else
// L293 code
void Motor_Forward(uint32_t dutyLeft, uint32_t dutyRight){
  GPIOB->DOUTCLR31_0 = DIR_L | DIR_R;  // forward
  PWM1_SetDuty(MOTOR_PERIOD-dutyLeft,MOTOR_PERIOD-dutyRight);
}

void Motor_Backward(uint32_t dutyLeft, uint32_t dutyRight){
  GPIOB->DOUTSET31_0 = DIR_L | DIR_R;  // backward
  PWM1_SetDuty(dutyLeft,dutyRight);
}
void Motor_Right(uint32_t dutyLeft, uint32_t dutyRight){
  GPIOB->DOUTCLR31_0 = DIR_L;  // left forward
  GPIOB->DOUTSET31_0 = DIR_R;  // right backward
  PWM1_SetDuty(MOTOR_PERIOD-dutyLeft,dutyRight);
}
void Motor_Left(uint32_t dutyLeft, uint32_t dutyRight){
  GPIOB->DOUTCLR31_0 = DIR_R;  // right forward
  GPIOB->DOUTSET31_0 = DIR_L;  // left backward
  PWM1_SetDuty(dutyLeft,MOTOR_PERIOD-dutyRight);
}
#endif

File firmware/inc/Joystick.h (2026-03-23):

/*!
 * @defgroup MKII
 * @brief MKII boosterpack joystick
 <table>
<caption id="MKIIjoystickpins">MKII Joystick pins </caption>
<tr><th>Pin <th>Function<th>Description
<tr><td>PA26<td>GPIO  <td>J1.5 joystick Select button (digital)   
<tr><td>PA15<td>ADC0.2<td>J1.2 joystick horizontal (X) (analog)     
<tr><td>PA18<td>ADC1.3<td>J1.10 ambient light (OPT3001) and temperature sensor (TMP006)    
<tr><td>PA12<td>GPIO  <td>J4.33 user Button1 (bottom) (digital)   
<tr><td>PA11<td>GPIO  <td>J4.32 user Button2 (top) (digital) (conflicts with UART0 Rx from XDS Tx)   
</table>
 * @{*/
/**
 * @file      JoyStick.h
 * @brief     Joystick on MKII boosterpack
 * @details   Software driver functions for joystick on MKII boosterpack<br>
 * https://www.ti.com/tool/BOOSTXL-EDUMKII <br>

 * @version   ECE319K v1.2
 * @author    Daniel Valvano and Jonathan Valvano
 * @copyright Copyright 2023 by Jonathan W. Valvano, valvano@mail.utexas.edu,
 * @warning   AS-IS
 * @note      For more information see  http://users.ece.utexas.edu/~valvano/
 * @date      December 23, 2024
 * \image html MKIIBoosterPack.png width=500px 
<br>
 <table>
<caption id="MKIIjoystickpins2">MKII Joystick pins </caption>
<tr><th>Pin <th>Function<th>Description
<tr><td>PA26<td>GPIO  <td>J1.5 joystick Select button (digital)   
<tr><td>PA15<td>ADC0.2<td>J1.2 joystick horizontal (X) (analog)     
<tr><td>PA18<td>ADC1.3<td>J1.10 ambient light (OPT3001) and temperature sensor (TMP006)    
<tr><td>PA12<td>GPIO  <td>J4.33 user Button1 (bottom) (digital)   
<tr><td>PA11<td>GPIO  <td>J4.32 user Button2 (top) (digital) (conflicts with UART0 Rx from XDS Tx)   
</table>
  ******************************************************************************/


#ifndef __JOYSTICK_H__
#define __JOYSTICK_H__
/**
 * Initialize MKII JoyStick, JoyStick button, and MKI button1 
 * @param none
 * @return none 
 * @see JoyStick_In() JoyStick_InButton() JoyStick_InButton1()
 * @brief  Initialize JoyStick
 * @note Button2 not initialized because it conflicts with UART0 Rx from XDS Tx
 */
void JoyStick_Init(void);


/**
 * Read JoyStick negative logic button. Input from MKII JoyStick button (pushing down on stick) 
 * @param none
 * @return 0 if pressed, nonzero if not pressed 
 * @see JoyStick_Init()
 * @brief  Input JoyStick button
 */
uint32_t JoyStick_InButton(void);


/**
 * ead JoyStick position (x,y) 
 * @param x pointer to empty 32 bit unsigned variable
 * @param y pointer to empty 32 bit unsigned variable
 * @return none 
 * @see JoyStick_Init()
 * @brief  Read JoyStick
 */
void JoyStick_In(uint32_t *x, uint32_t *y);

// Read Button1 button (bottom)
// Input: none
// Output: 0 if pressed, nonzero if not pressed
/**
 * Read Button1 button on MKII  
 * @param none
 * @return 0 if pressed, nonzero if not pressed 
 * @see JoyStick_Init()
 * @brief  Input MKII button1
 * @note Button2 not initialized because it conflicts with UART0 Rx from XDS Tx
 */
uint32_t JoyStick_InButton1(void);


#endif
/** @}*/

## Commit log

2026-03-03 cleaned up unnecessary files
    [periph_board.kicad_sch]
2026-03-05 scorched earth
    [9032joystick.stp, BOMv2.xlsx, ECE319K_Starter.kicad_pcb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]
2026-03-07 Adjusted spacing to 13.5mm between hall effects
    [HALL_ARR.kicad_sch, periph_board.kicad_pcb, periph_board.kicad_sch]
2026-03-08 fixed sides of peripheral board not being symmetrical. added teardrops. name of board tbd
    [MCU.kicad_sch, POWER.kicad_sch, periph_board.kicad_sch]
2026-03-09 drew schematic
    [AUDIO_IO.kicad_sch, ENCODERS_BUTTONS.kicad_sch, LCD.kicad_sch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]
2026-03-10 save before nuke SPI ADC
    [AUDIO_IO.kicad_sch, ENCODERS_BUTTONS.kicad_sch, LCD.kicad_sch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]
2026-03-11 port to i2c for both boards. periph board passes drc
    [HALL_ARR.kicad_sch, LCD.kicad_sch, MCU.kicad_sch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]
2026-03-23 project builds
    [OPT3101speedChoices.xlsx, SineTable.xlsx]
2026-03-29 finished main pcb
    [LED_STRIPS.kicad_sch, POWER.kicad_sch, periph_board.kicad_sch]
2026-03-31 prod files
    [AUDIO_IO.kicad_sch]
